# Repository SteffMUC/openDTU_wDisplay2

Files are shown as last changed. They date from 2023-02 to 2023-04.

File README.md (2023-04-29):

# openDTU_wDisplay2 

* Small PCB for [openDTU](https://github.com/tbnobody/OpenDTU)
* Based on idea/ realization of [breakout board](https://github.com/dokuhn/openDTU-BreakoutBoard)
* 2nd version with much smaller PCB [1st version](https://github.com/SteffMUC/openDTU_wDisplay)
* The PCB has the ESP32 on backside, Display and nRF24l01 on frontside.
* Dedicated case available in [openscad](https://github.com/SteffMUC/openDTU_wDisplay2/tree/main/openscad) directory
* Configuration file [nodemcu_esp32.json](https://github.com/tbnobody/OpenDTU/blob/master/docs/DeviceProfiles/nodemcu_esp32.json) available in [openDTU](https://github.com/tbnobody/OpenDTU), please select "Generic NodeMCU 32 with SSD1306" as profile
* In case you struggle how to configure [openDTU](https://github.com/tbnobody/OpenDTU), the documentation can be found here [openDTU Display documentation](https://github.com/tbnobody/OpenDTU/blob/master/docs/Display.md)
* The PCB is designed to work with ESP32S NodeMCU (38 Pins) e.g. [Amazon](https://www.amazon.de/gp/product/B0BF5NRF8H/ref=ppx_yo_dt_b_search_asin_title?ie=UTF8&th=1)

## Picture of model:
<p float="left">
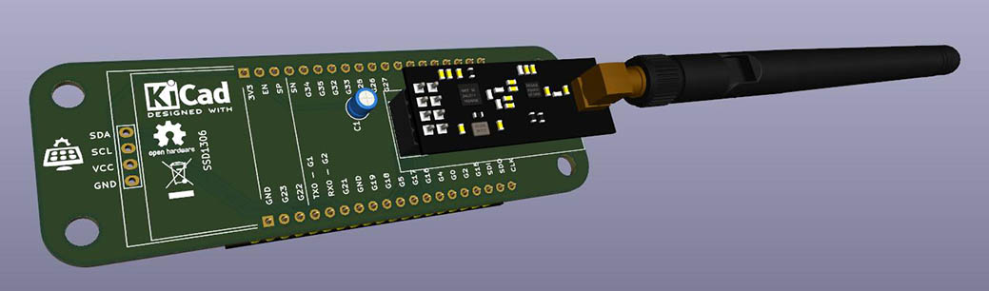
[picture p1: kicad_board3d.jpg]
Board Model
  
</p>

## Final printed case with display mounted on the side of a small IKEA Besta cupboard:
<p float="left">
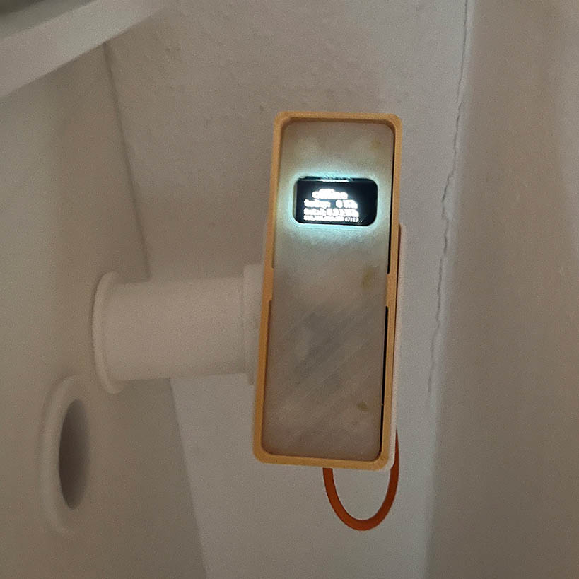
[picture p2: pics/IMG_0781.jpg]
Final assembly
  
</p>

## PCB assembly:
<p float="left">
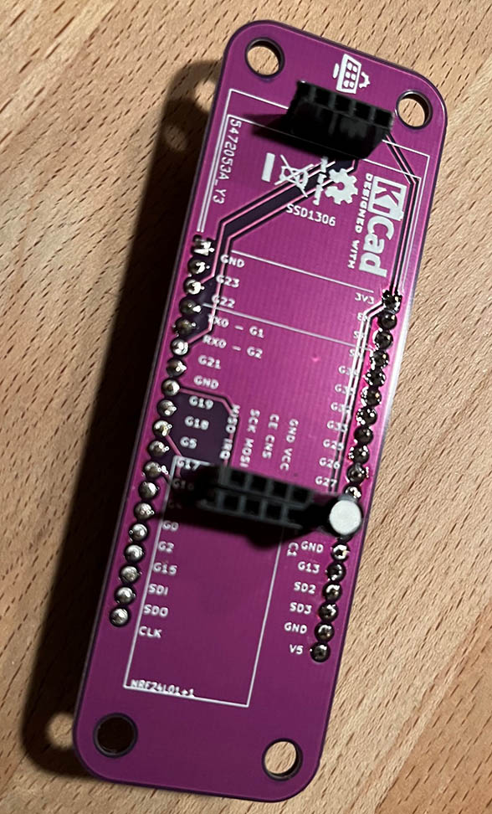
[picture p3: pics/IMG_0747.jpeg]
  
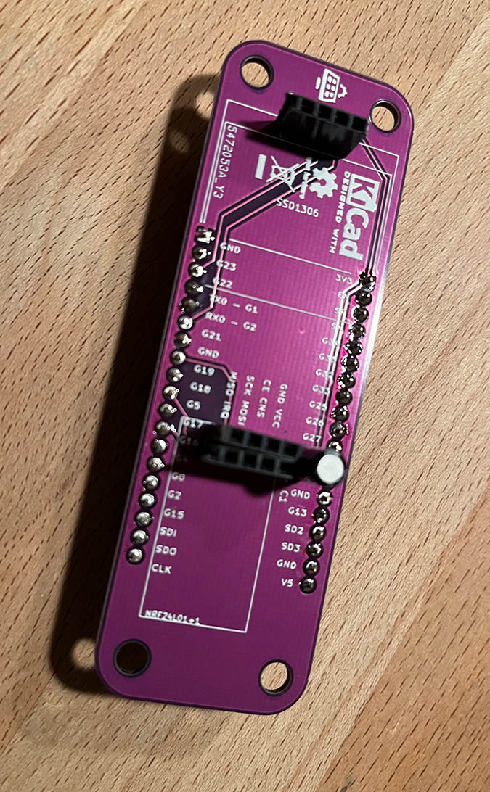
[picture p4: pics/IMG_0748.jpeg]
  
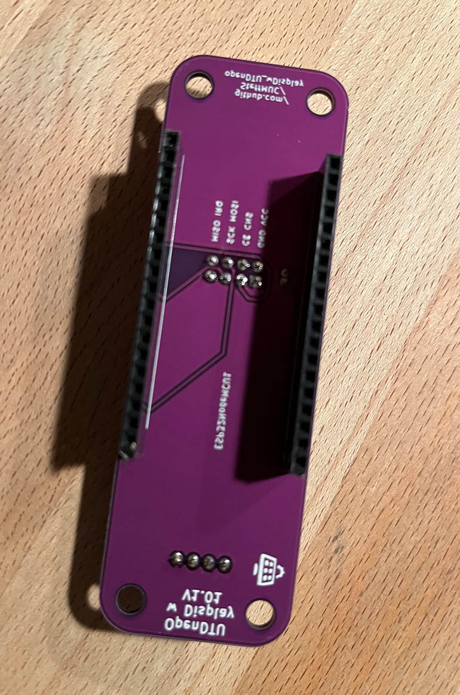
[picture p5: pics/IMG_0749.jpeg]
  
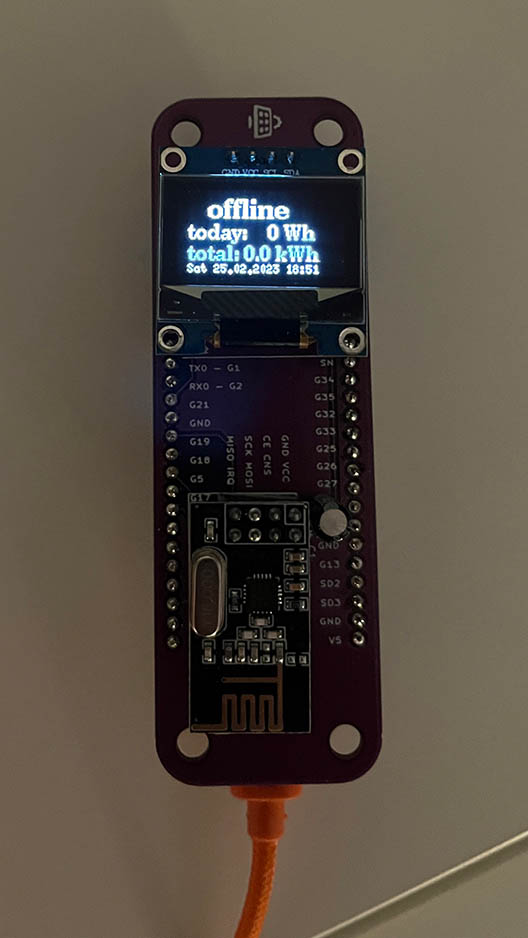
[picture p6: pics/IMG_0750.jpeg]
  
</p>

## History:

* 2023-02-28: boards received, soldered, working reliable, pics in picture folder, case currently in progress - not yet perfectly fitting 

* 2023-03-01: Final printing of case done, got some requests for spare PCBs, all spare PCBs now gone, if you need a PCB, you can easily upload the gerber zip file on any PCB manufacturer, e.g. PLCPCB (10 pieces, with customs to Germany in 2 weeks roughly 14 EUR).

* 2023-03-11: Accepted pull request from @Nightreaver, thanks for the contribution, backside silk screen now mirrored, nRF footprint changed by @Nightreaver to support nRF+ with antenna (Note: openscad case not adapted and currently not planned to be adapted)

In case you are looking for a cheap source for the capacitors, I ordered mine with Christians_Shop at [Amazon](https://www.amazon.de/gp/product/B01MTSDA58/ref=ppx_yo_dt_b_search_asin_title?ie=UTF8&psc=1) (they have a direct website as well).

## 3D Print:
Everything can be printed without support, expect for the ikea holder:
<p float="left">
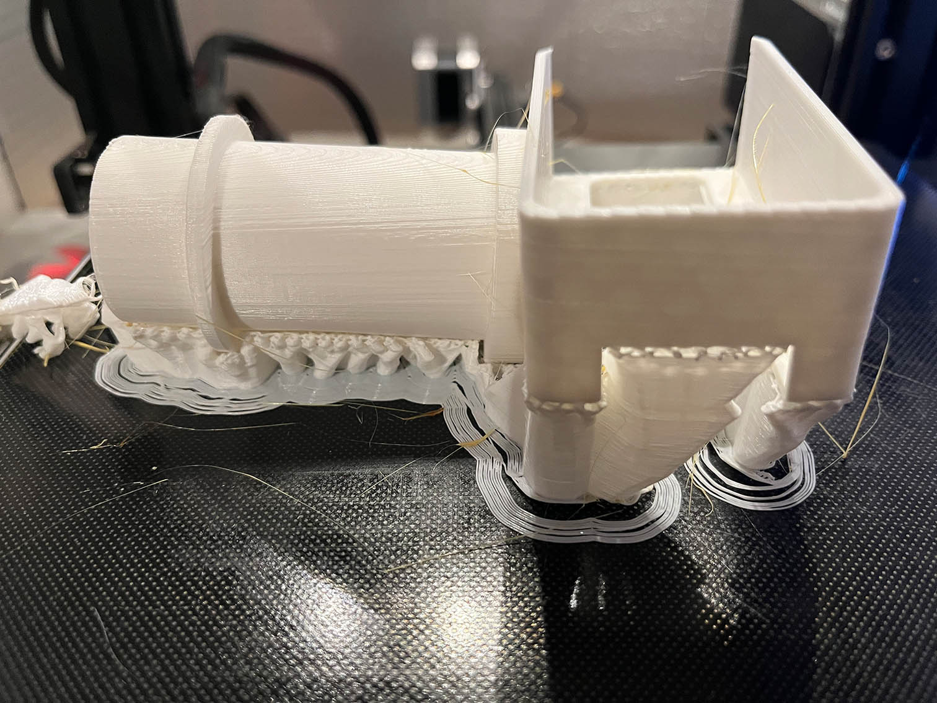
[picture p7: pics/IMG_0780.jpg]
Ikea holder with support structure
  
</p>

## Known limitations: 
* Backside silkscreen is not mirrored, in Kicad, still needs to be fixed, result is mirrored text on backside (for new orders). --> Fixed now
* If you print the case: The holders for the PCB are not yet perfectly aligned (need 0.5mm adjust), I "clipped" 3 of them away to avoid reprinting.

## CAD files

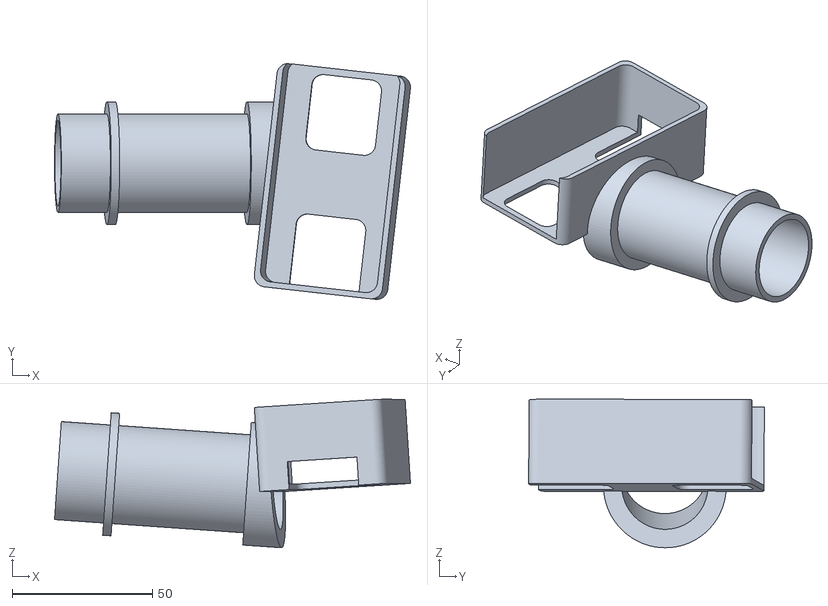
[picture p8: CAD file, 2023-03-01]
openscad/opendtu_holder_ikea.stl
126.8 x 84.0 x 52.9

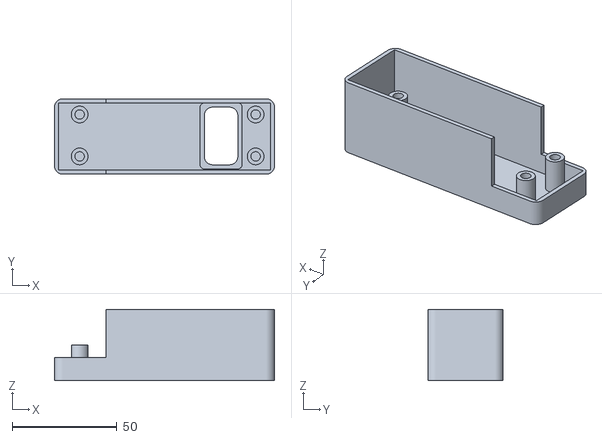
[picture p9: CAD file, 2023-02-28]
openscad/opendtu_top.stl
105.0 x 36.0 x 34.0

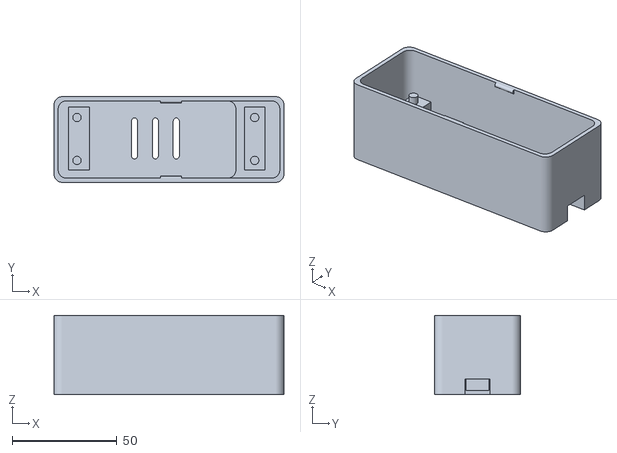
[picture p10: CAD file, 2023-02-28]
openscad/opendtu_body.stl
110.0 x 41.0 x 38.0

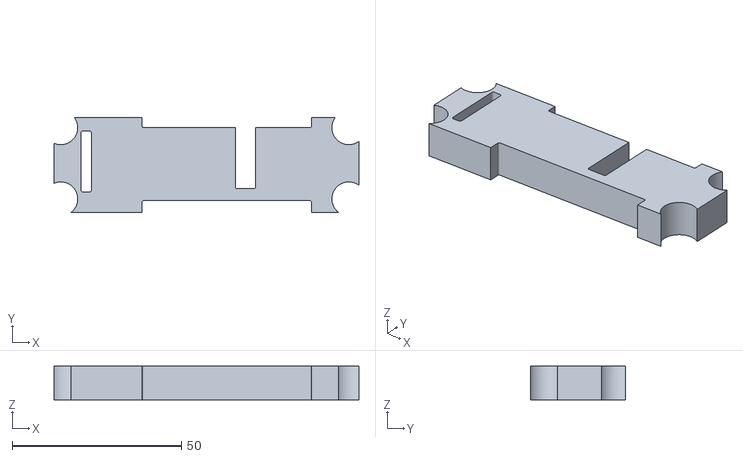
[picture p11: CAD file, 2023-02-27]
openscad/opendtu_spacer.stl
90.0 x 28.0 x 10.0

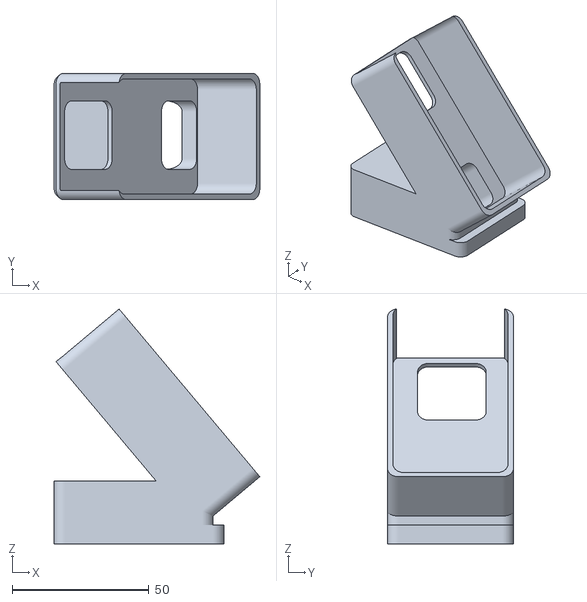
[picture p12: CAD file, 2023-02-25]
openscad/opendtu_holder.stl
75.1 x 46.0 x 85.8

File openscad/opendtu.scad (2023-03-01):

$fn=100;

part="ikea"; // body OR top OR body_top_debug OR top_printable OR spacer OR holder OR ikea
debug="false"; // true OR false

if (debug == "true") {
    #translate([0,0,7])opendtu_pcb(); // rough model for pcb w esp32+nrf+display
}

if (part == "holder_ikea"){
    case_body();
}

else if (part == "top"){
    case_top();
}

else if (part == "body_top_debug"){
    #translate([0,0,7])opendtu_pcb();
    case_body();
    translate([0,0,19])spacer();
    case_top();
    }

else if (part == "top_printable"){
    rotate([0,180,0]) 
    case_top();
}

else if (part == "spacer"){
    if (debug == "true") {translate([-96,0,-30])spacer();} 
    else {spacer();}

}

else if (part == "holder"){
    rotate([0,50,0]) translate([69,-2.5,-2.5])case_holder();
}

else if (part == "ikea"){
    rotate([-50,4,0]) translate([0,0,0])case_holder_ikea();
}

else{ // print all - except holder
	translate([10,0,0]) case_body();
    translate([100,50,36]) rotate([0,180,0]) case_top();
    translate([0,-50,0]) spacer();
}


module case_holder_ikea(){
	if (debug == "true") {
        #translate([-18,-30,0]) cube([18,3,3]);// debug        
        translate([-18,-15,0]) cube([3,30,3]);// debug        
        //translate([-18,-17.5,0]) cube([3,35,3]);// debug        
    }
    rotate([0,270,0]) union(){
		difference(){
			union(){
                translate([0,0,-1.5]) cylinder(r=(35/2)*1.25, h=3, center=true);
                translate([0,0,-60]) cylinder(r=(35/2)*1.25, h=20, center=true);
                translate([0,0,-22.5]) cylinder(r=(35/2), h=80, center=true);
            }
			cylinder(r=(35/2)/1.14, h=200, center=true);
            rotate([-10,0,0]) translate([-40,-40,-75]) roundedcube(80,80,15,4);
		}
	}
    
    //------------------------holder
    rotate([0,50,260]) translate([0,64,-10]) difference() {
        translate([-42.5,-6,0]) roundedcube(80,46,30,4);
        translate([-43.5,-4,2]) roundedcube(79,42,30,4);
        translate([10,5,-20]) roundedcube(40,25,30,4);
        translate([-40,5,-0.5]) roundedcube(27,25,30,4);
    }
}


module case_holder() {

//------------------------holder
difference() {
    union() {
        translate([-42.5,-6,0]) roundedcube(80,46,30,4);
        difference() {
            rotate([0,-50,0]) translate([-28,-6,-34]) roundedcube(62,46,7,4);
            rotate([0,-50,0]) translate([-36,12,-34.5]) roundedcube(55,10,7,1);
            rotate([0,-50,0]) translate([0,2,-34.5]) roundedcube(20,30,7,1);
        }
        rotate([0,-50,0]) translate([-28,-6,-30]) roundedcube(58,46,7,4);
        rotate([0,-50,0]) translate([-28,-6,-26]) roundedcube(58,46,7,4);
        rotate([0,-50,0]) translate([-28,-6,-22]) roundedcube(58,46,7,4);
        rotate([0,-50,0]) translate([-28,-6,-18]) roundedcube(58,46,7,4);
    }
    translate([-43.5,-4,2]) roundedcube(79,42,30,4);
    translate([15,5,-20]) roundedcube(20,25,30,4);
    translate([-40,5,-0.5]) roundedcube(27,25,30,4);
}

}


module spacer() {

    //------------------------spacer display
    difference() {
        translate([3,0,0]) roundedcube(90,28,10,2);
        translate([11,6,-0.5]) roundedcube(3,18,11,0.5);
        translate([56.5,7,-0.5]) roundedcube(6,19,11,0.5);
        translate([29,-0.5,-0.5]) roundedcube(50,4,11,0.5);
        translate([29,25,-0.5]) roundedcube(50,4,11,0.5);

        //------------------------cutouts for stamps of case top
        //bottom right
        translate([90,4,-0.5]) scale([1,1,1]) cylinder(h=14, d=10, center=false);
        //top right
        translate([90,25,-0.5]) scale([1,1,1]) cylinder(h=14, d=10, center=false);
        //top left
        translate([5,25,-0.5]) scale([1,1,1]) cylinder(h=14, d=10, center=false);
        //bottom left
        translate([5,4,-0.5]) scale([1,1,1]) cylinder(h=14, d=10, center=false);

    }

}


module case_body() {

//------------------------stamps for pcb
//bottom right
translate([89,4.5,2]) scale([1,1,1]) cylinder(h=19, d=4, center=false);
translate([84,0,7.5]) scale([1,1,1]) cube([10,30,10]);
//translate([90.5,4.5,2]) scale([1,1,1]) cylinder(h=15.5, d=8, center=false);
//top right
translate([89,25,2]) scale([1,1,1]) cylinder(h=19, d=4, center=false);
//translate([90.5,25,2]) scale([1,1,1]) cylinder(h=15.5, d=8, center=false);
//top left
translate([4,25,2]) scale([1,1,1]) cylinder(h=19, d=4, center=false);
translate([0,0,2]) scale([1,1,1]) cube([10,30,15.5]);
//translate([4.5,25,2]) scale([1,1,1]) cylinder(h=15.5, d=8, center=false);
//bottom left
translate([4,4.5,2]) scale([1,1,1]) cylinder(h=19, d=4, center=false);
//translate([4.5,4.5,2]) scale([1,1,1]) cylinder(h=15.5, d=8, center=false);


//------------------------case body (+6)
rotate([0,90,0]) translate([-37,-4,44]) cylinder(h=10,d=2,center=false); //notches for top
rotate([0,90,0]) translate([-37,33,44]) cylinder(h=10,d=2,center=false);
difference() {
    //translate([-4,-6,0]) roundedcube(107,41,36,4);
    translate([-7,-6,0]) roundedcube(110,41,38,4);
    //translate([-2,-4,2]) roundedcube(82,37,36,4);
    translate([-5,-4,2]) roundedcube(85,37,38,4);
    //translate([-2,-4,10]) roundedcube(103,37,36,4);
    translate([-5,-4,10]) roundedcube(106,37,38,4);
    translate([80,8.5,-0.5]) roundedcube(50,12,8,0.5); // usb cable
    rotate([90,0,90])translate([10,1.5,80]) roundedcube(10,5,3,1); // usb plug
    if (debug == "true") {
        translate([65,-6.5,2]) roundedcube(27.5,3,30,2);// debug
        translate([-8,0,0]) roundedcube(5,25,25,2);// debug        
    }
    translate([30,5,-0.5]) roundedcube(3,20,30,2);// cutout esp32
    translate([40,5,-0.5]) roundedcube(3,20,30,2);// cutout esp32
    translate([50,5,-0.5]) roundedcube(3,20,30,2);// cutout esp32
}

}

module case_top() {

//------------------------case top (leave 1mm gap to body)
difference() {
    //translate([-1.5,-3.5,2]) roundedcube(102,36,32,4); 
    translate([-4.5,-3.5,2]) roundedcube(105,36,34,4); 
    //translate([0.5,-1.5,1.5]) cube([98,32,30.5]); 
    translate([-2.5,-1.5,1.5]) cube([101,32,32.5]); 
    if (debug == "true") {
        translate([-2,-4,1.5]) roundedcube(110,60,30.5,4); //debug needs commented
    }
    translate([13,1,10]) roundedcube(16,27.5,30,4);// cutout display
    //translate([15,10,2]) roundedcube(27.5,3,30,2);// cutout esp32 + nrf
    //translate([15,20,2]) roundedcube(27.5,3,30,2);
    //translate([15,30,2]) roundedcube(27.5,3,30,2);
    //translate([15,40,2]) roundedcube(27.5,3,30,2);
    translate([76,-5,1.5])cube([32,60,23.5]); //cutout usb
    //translate([103,-5,1.5])cube([32,60,23.5]); //debug cutout needs to be commented

    //translate([56,26,-5]) scale([1,1,1]) cylinder(h=20, d=17, center=true);
}

//------------------------case top, frame for display
difference() {
    translate([11,-1,32]) roundedcube(20,31.5,2,2); 
    translate([13,1,31.5]) roundedcube(16,27.5,30,4);// cutout display
}

//------------------------stamps for case top
//bottom right
difference() {
    translate([88.5,5,19]) scale([1,1,1]) cylinder(h=16, d=8, center=false);
    translate([88.5,5,2]) scale([1,1,1]) cylinder(h=20, d=4.5, center=false);
}
//top right
difference() {
    translate([88.5,25,19]) scale([1,1,1]) cylinder(h=16, d=8, center=false);
    translate([88.5,25,2]) scale([1,1,1]) cylinder(h=20, d=4.5, center=false);
}
//top left
difference() {
    translate([4.5,25,19]) scale([1,1,1]) cylinder(h=16, d=8, center=false);
    translate([4.5,25,2]) scale([1,1,1]) cylinder(h=20, d=4.5, center=false);
}
//bottom left
difference() {
    translate([4.5,5,19]) scale([1,1,1]) cylinder(h=16, d=8, center=false);
    translate([4.5,5,2]) scale([1,1,1]) cylinder(h=20, d=4.5, center=false);
}

}


module opendtu_pcb() {
    translate([-90,100,11]) scale([1000,1000,1000]) import("openDTU_wDisplay.stl"/*, convexity=3*/);
    /*
    //esp32
    translate([10,-4,2])cube([28,55,14]);
    translate([20.5,-5,14])cube([8,6,3]);*/
    //nrf
        translate([57,6,11.5])cube([30,15,17]);
    //display
        translate([8,1,11.5])cube([27.5,27.5,13]);
    //translate([59,13.5+9,2])cube([27.5,16,17]);
    /*difference(){*/
        //cube([96,31,2]); //pcb
        /*//bottom left
        translate([2.5+2.25,2.5+2.25,-0.5]) cylinder(h=10,d=4.5,center=false); 
        //bottom right
        translate([2.5+99-2.25,2.5+2.25,-0.5]) cylinder(h=10,d=4.5,center=true);
        //top left
        translate([2.5+2.25,2.5+45-2.25,-0.5]) cylinder(h=10,d=4.5,center=false);
        //top right
        translate([2.5+99-2.25,2.5+45-2.25,-0.5]) cylinder(h=10,d=4.5,center=true);

    }*/
}


module roundedcube(xx, yy, height, radius) {

difference(){

    cube([xx,yy,height]);

    difference(){
        translate([-.5,-.5,-.2])
        cube([radius+.5,radius+.5,height+.5]);

        translate([radius,radius,height/2])
        cylinder(height,radius,radius,true);
    }
    translate([xx,0,0])
    rotate(90)
    difference(){
        translate([-.5,-.5,-.2])
        cube([radius+.5,radius+.5,height+.5]);
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

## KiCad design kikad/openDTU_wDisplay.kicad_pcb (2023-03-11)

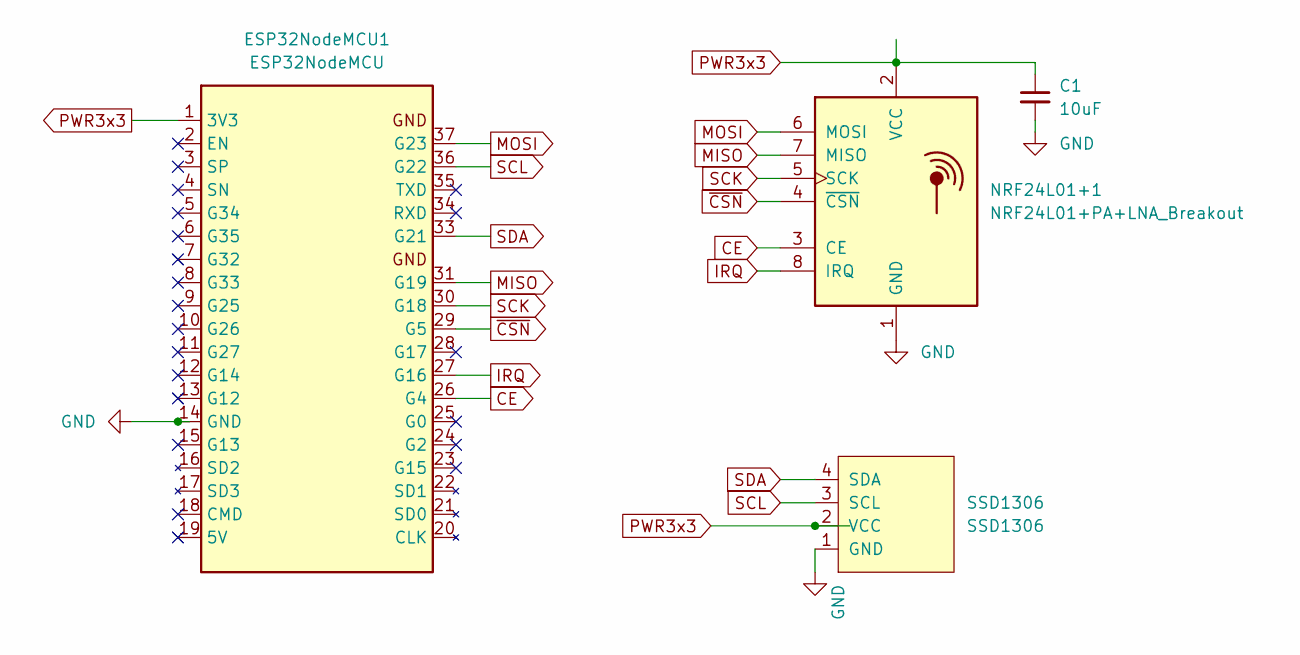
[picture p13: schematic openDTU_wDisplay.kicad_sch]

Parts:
C1: 10uF; C_Radial_D4.0mm_H5.0mm_P1.50mm
ESP32NodeMCU1: ESP32NodeMCU; ESP32-NodeMCU_WROOM_32
NRF24L01+1: NRF24L01+PA+LNA_Breakout; nRF24L01+PA+LNA_Breakout
SSD1306: SSD1306; 128x64OLED

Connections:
CE: ESP32NodeMCU1.26 (G4), NRF24L01+1.3 (CE)
GND: C1.2, ESP32NodeMCU1.14 (GND), ESP32NodeMCU1.32 (GND), ESP32NodeMCU1.38 (GND), NRF24L01+1.1 (GND), SSD1306.1 (GND)
IRQ: ESP32NodeMCU1.27 (G16), NRF24L01+1.8 (IRQ)
MISO: ESP32NodeMCU1.31 (G19), NRF24L01+1.7 (MISO)
MOSI: ESP32NodeMCU1.37 (G23), NRF24L01+1.6 (MOSI)
PWR3x3: C1.1, ESP32NodeMCU1.1 (3V3), NRF24L01+1.2 (VCC), SSD1306.2 (VCC)
SCK: ESP32NodeMCU1.30 (G18), NRF24L01+1.5 (SCK)
SCL: ESP32NodeMCU1.36 (G22), SSD1306.3 (SCL)
SDA: ESP32NodeMCU1.33 (G21), SSD1306.4 (SDA)
~CSN: ESP32NodeMCU1.29 (G5), NRF24L01+1.4 (~CSN)

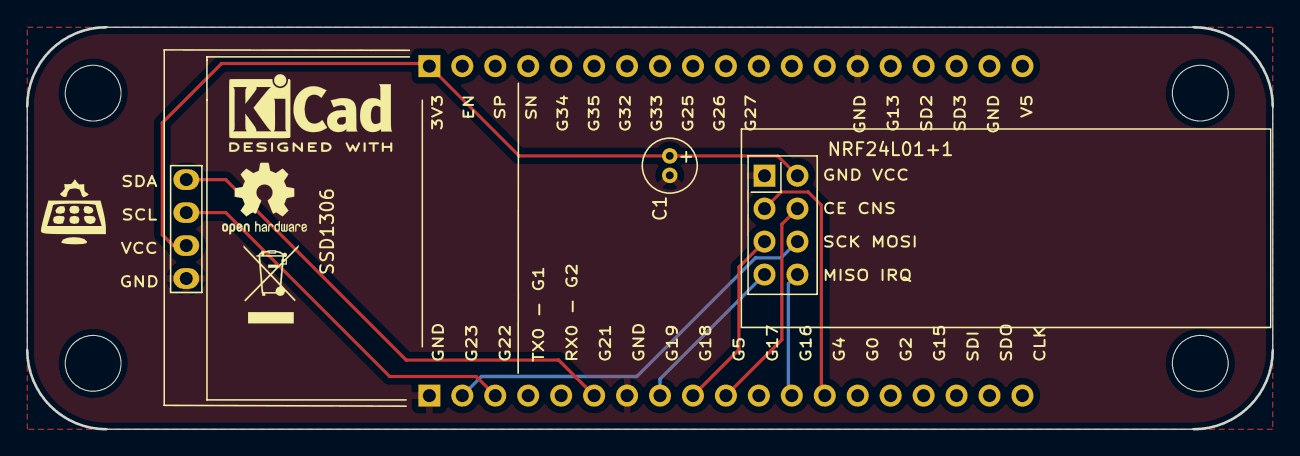
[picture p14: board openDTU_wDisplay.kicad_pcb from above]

Board: 2 copper layers, 96.0 x 31.0 mm, 4 parts (1 on the bottom side), 10 nets.

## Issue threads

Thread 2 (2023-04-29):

Improve project description

BabyFnord, 2023-04-29:
Hi there,

some may find themselves lost when starting from scratch with OpenDTU + OLED display on a breakout board, as learning about and/or choosing a suitable setup or profile is tricky, due to the many hardware variants out there. I had a bumpy start because I did not order a 38-pin ESP32 module at first (PCBs were still being produced at the time I ordered the required parts, I did not have KiCad at that time), and I only found out about uploading [nodemcu_esp32.json](https://github.com/tbnobody/OpenDTU/blob/master/docs/DeviceProfiles/nodemcu_esp32.json) as `Pin Mapping` by trial and error. Hence my suggestion to include the required ESP32 module type _and_ a link to the required device profile in the project description.

At least I would suggest that including those notes help in getting folks jump on this project.

Thanks for sharing! 🙌

SteffMUC, 2023-04-29:
Fixed in https://github.com/SteffMUC/openDTU_wDisplay2/commit/ca8b40e09506fc29c84bab7fd1e2ed9f67b026da

SteffMUC, 2023-04-29:
Improved readme with extension of this information:
Configuration file [nodemcu_esp32.json](https://github.com/tbnobody/OpenDTU/blob/master/docs/DeviceProfiles/nodemcu_esp32.json) available in [openDTU](https://github.com/tbnobody/OpenDTU), please select "Generic NodeMCU 32 with SSD1306" as profile
In case you struggle how to configure [openDTU](https://github.com/tbnobody/OpenDTU), the documentation can be found here [openDTU Display documentation](https://github.com/tbnobody/OpenDTU/blob/master/docs/Display.md)
The PCB is designed to work with ESP32S NodeMCU (38 Pins) e.g. [Amazon](https://www.amazon.de/gp/product/B0BF5NRF8H/ref=ppx_yo_dt_b_search_asin_title?ie=UTF8&th=1)

Closed 2023-04-29.

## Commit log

2023-02-16 stl plus wrl model exported
2023-02-17 v2 case 1st draft
    [opendtu.scad, opendtu_body.stl, opendtu_top.stl]
2023-02-25 holder + spacer
    [opendtu.scad, opendtu_holder.stl, opendtu_spacer.stl]
2023-02-27 new pics
    [opendtu.scad, opendtu_body.stl, opendtu_spacer.stl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]
2023-02-27 adaption of display location
    [opendtu.scad, opendtu_body.stl, opendtu_holder_ikea.stl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]
2023-02-28 case corrections
    [opendtu.scad, opendtu_body.stl, opendtu_top.stl]
2023-02-28 adapt ikea holder
    [opendtu.scad, opendtu_holder_ikea.stl]
2023-03-01 change angle for ikea holder
    [opendtu.scad, opendtu_holder_ikea.stl]
2023-03-10 add support for NRF with external antenna shrink photos
    [openDTU_wDisplay-B_Cu.gbr, openDTU_wDisplay-B_Mask.gbr, openDTU_wDisplay-B_Paste.gbr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]

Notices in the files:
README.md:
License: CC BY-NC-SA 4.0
